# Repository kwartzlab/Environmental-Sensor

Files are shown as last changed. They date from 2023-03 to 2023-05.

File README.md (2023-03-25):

# Kwartzlab Environmental Sensor

The Kwartzlab Environemntal Sensor is a sensor board that is powered by an ESP32 which sends environmental metrics to grafana over wifi.

## Sensors
* [SHTC3 Humidity and Temperature Sensor](datasheets/SHTC3.pdf)
* [BME688 Gas Sensor](datasheets/BME688.pdf)
* [SPS30 Air Quality Sensor](datasheets/SPS30.pdf)
* [Zio Loudness Sensor](https://www.smart-prototyping.com/blog/Zio-Loudness-Sensor-Qwiic-Start-Guide)

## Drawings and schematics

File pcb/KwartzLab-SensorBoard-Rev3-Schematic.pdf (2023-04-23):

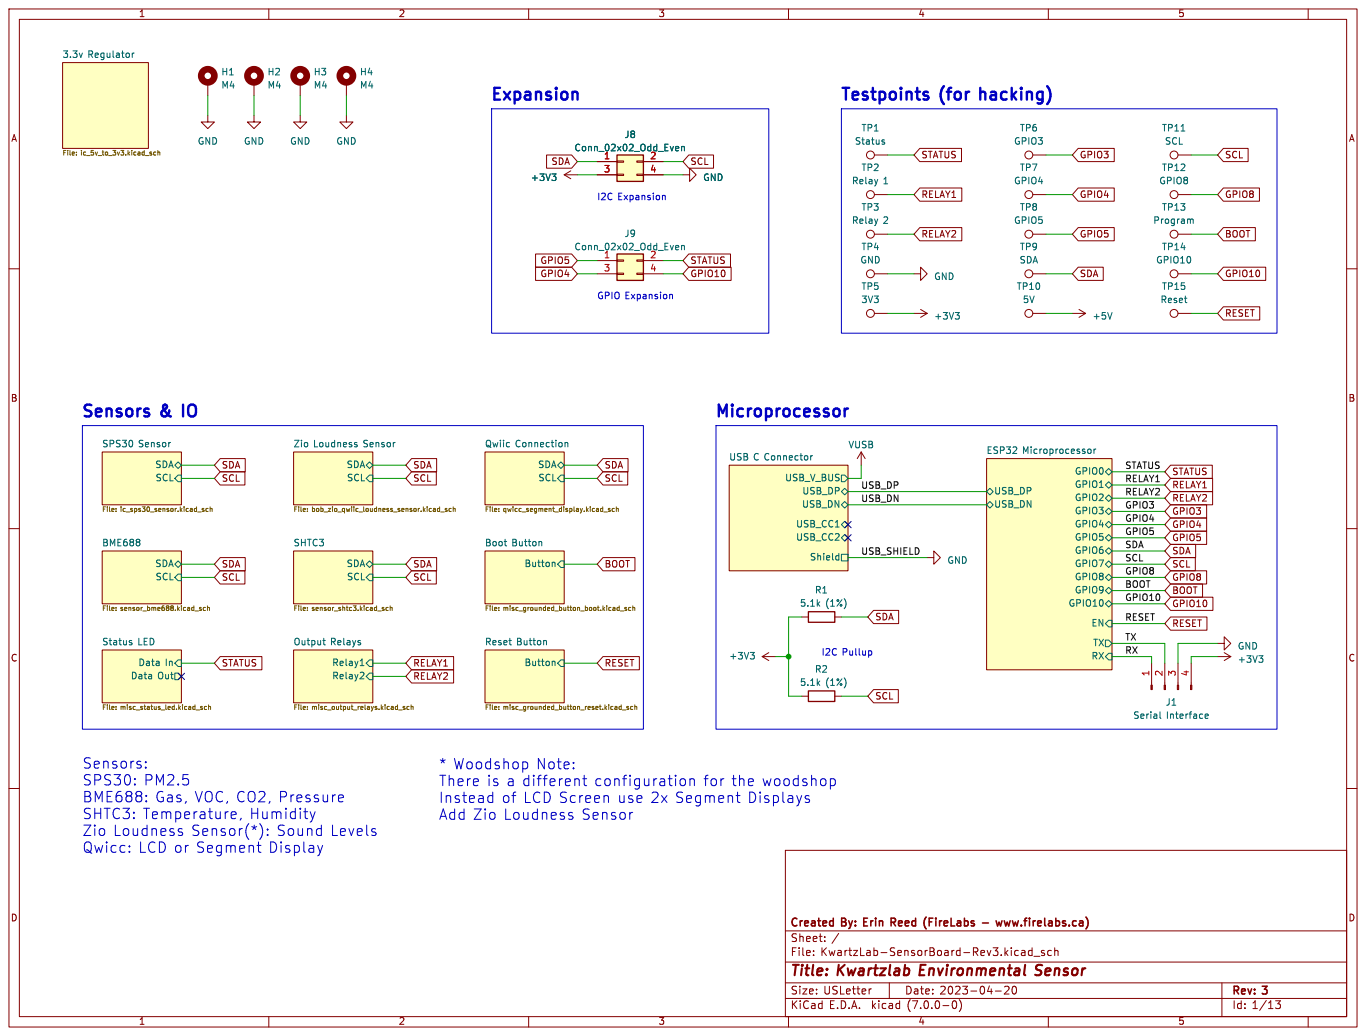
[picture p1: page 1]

File: misc_grounded_button_reset.kicad_sch SCL SDA Qwiic Connection

Zio Loudness Sensor File: bob_zio_qwiic_loudness_sensor.kicad_sch Relay1

STATUS RELAY1 GPIO3 RELAY2 GPIO5 GPIO4 GPIO10 BOOT SCL RESET RX

File: qwicc_segment_display.kicad_sch Button Boot Button

File: misc_output_relays.kicad_sch Data In Data Out Status LED

Sensors:
SPS30: PM2.5
BME688: Gas, VOC, CO2, Pressure
SHTC3: Temperature, Humidity
Zio Loudness Sensor(*): Sound Levels
Qwicc: LCD or Segment Display

Instead of LCD Screen use 2x Segment Displays
Add Zio Loudness Sensor

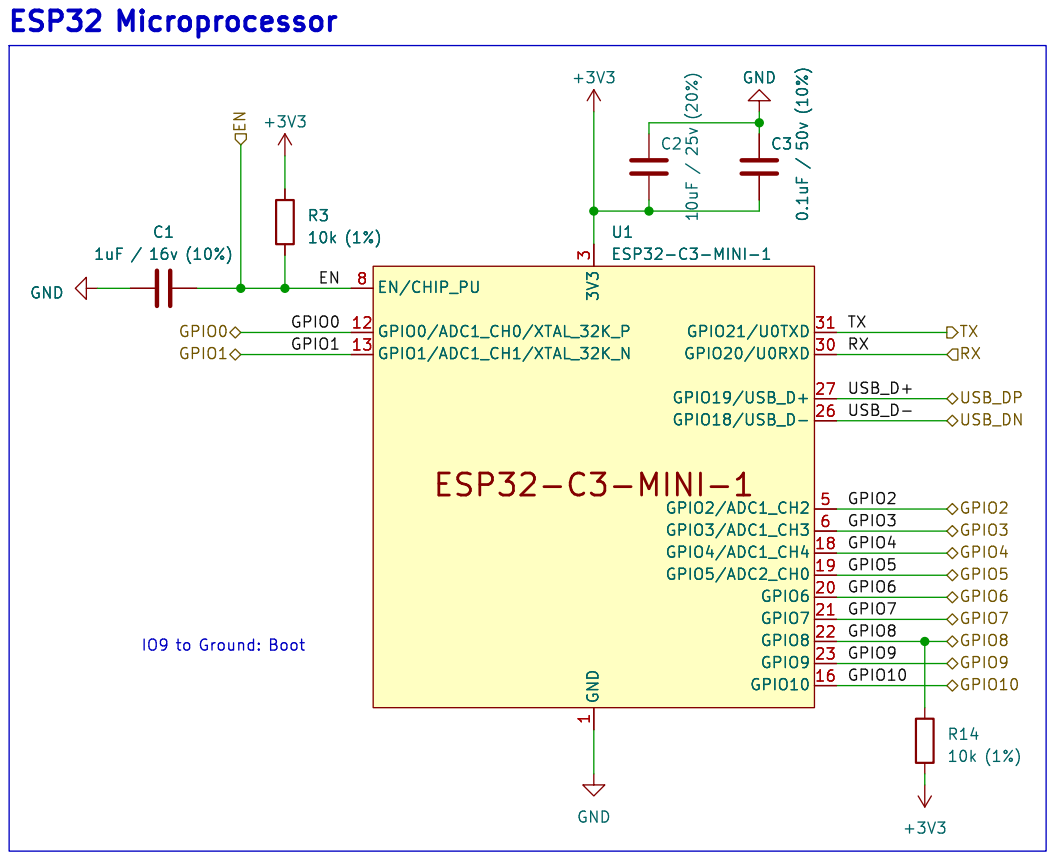
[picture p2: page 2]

IO9 to Ground: Boot ESP32 Microprocessor C1
C3 0.1uF / 50v (10%) U1ESP32-C3-MINI-1 GND

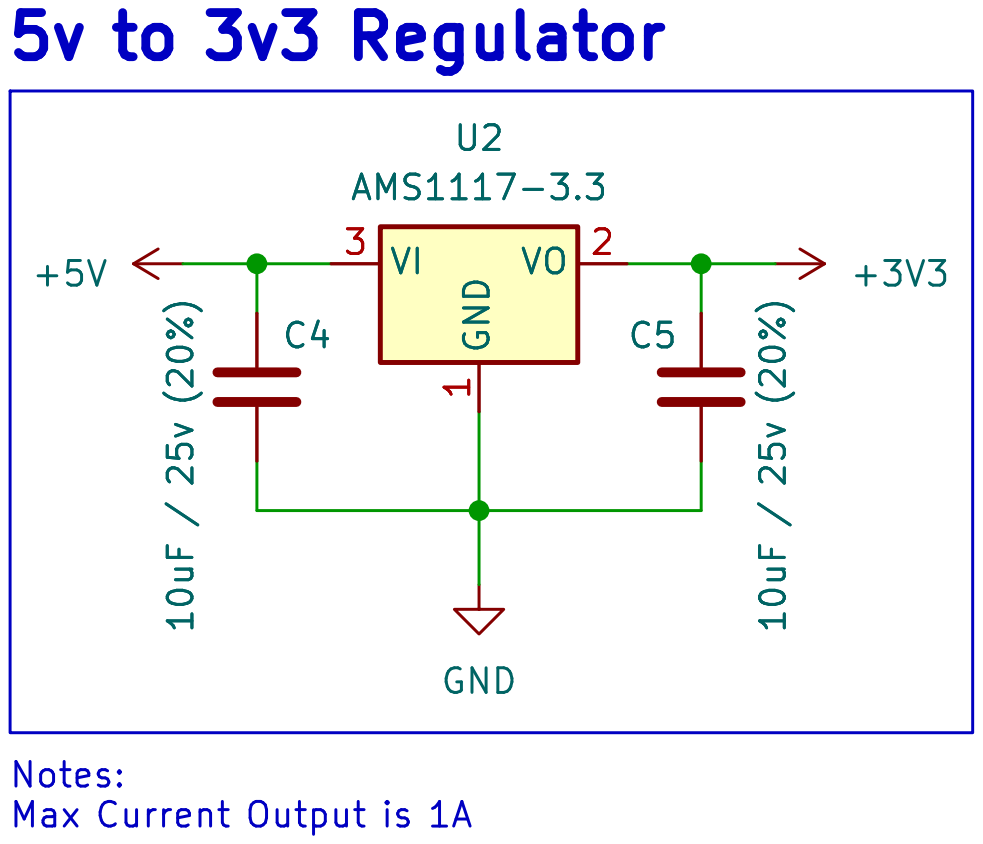
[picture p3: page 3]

1 VO 2 VI 3 U2 AMS1117-3.3 5v to 3v3 Regulator Notes: Max Current Output is 1A C4 10uF / 25v (20%) C5 10uF / 25v (20%) U2 AMS1117-3.3 GND

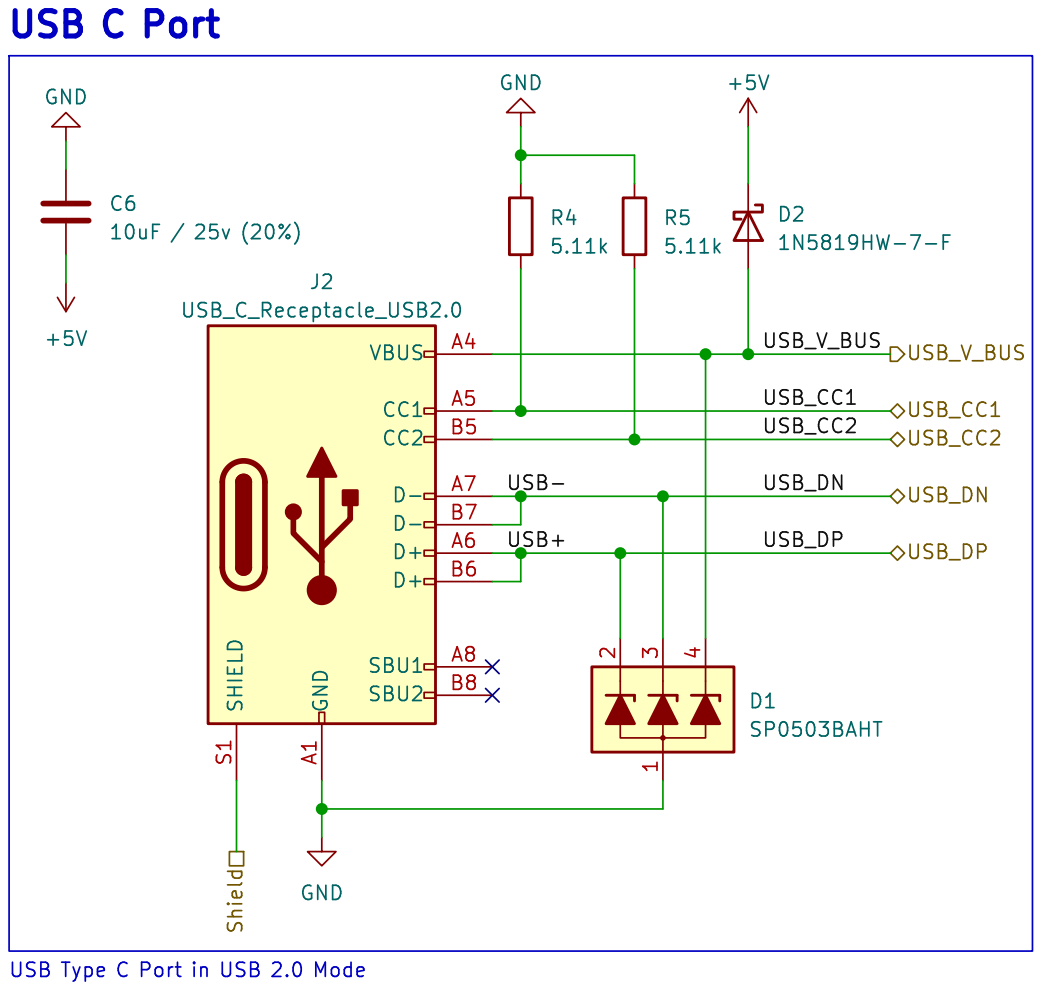
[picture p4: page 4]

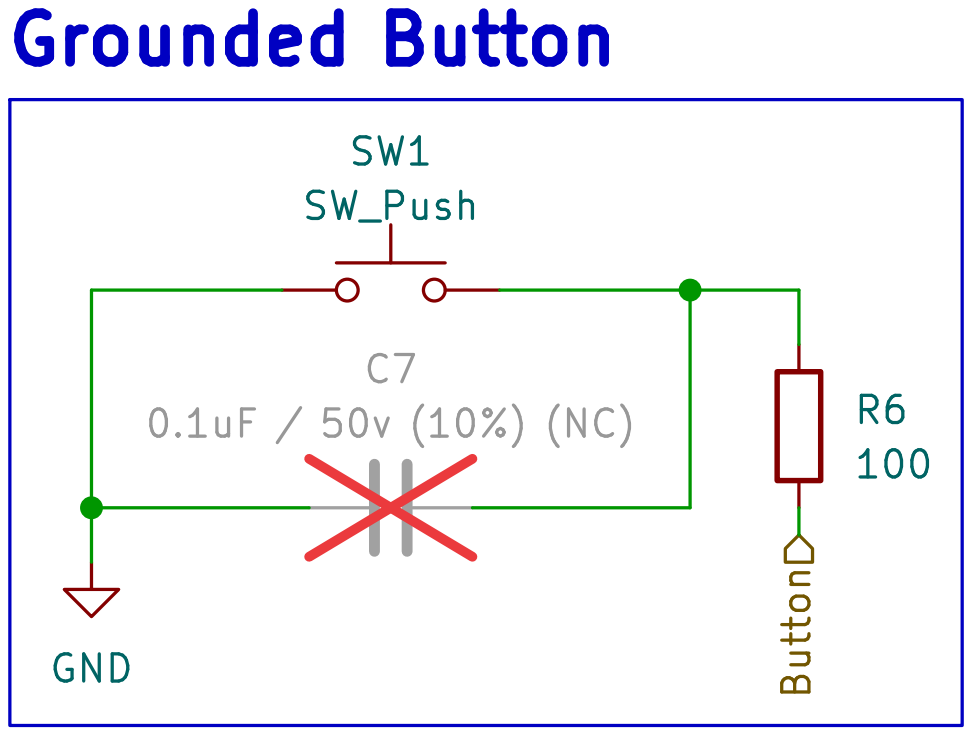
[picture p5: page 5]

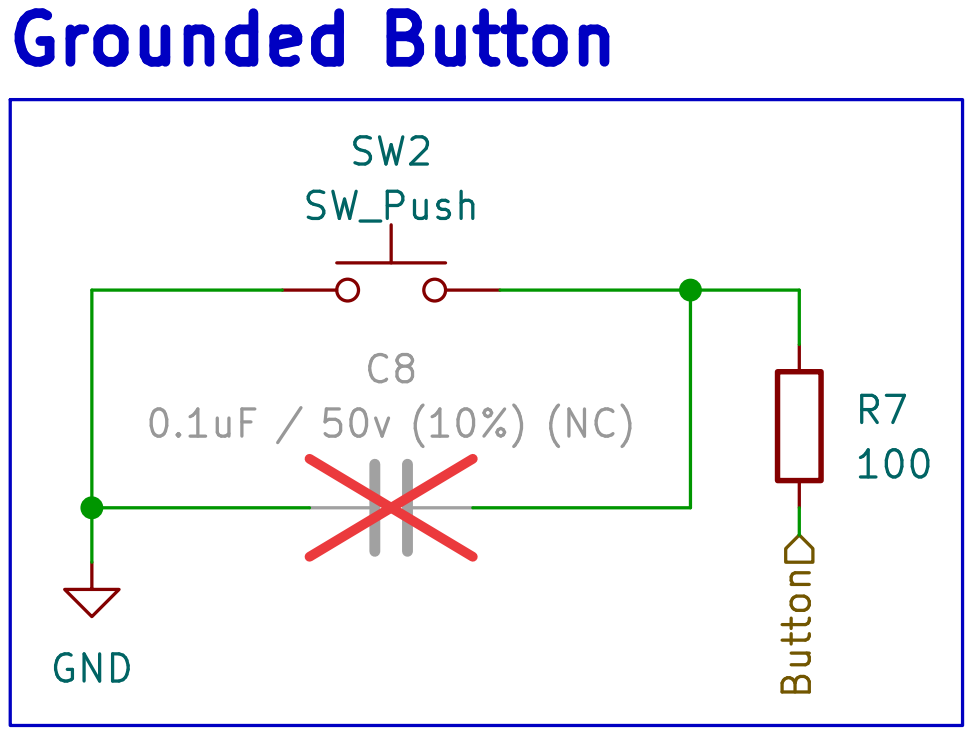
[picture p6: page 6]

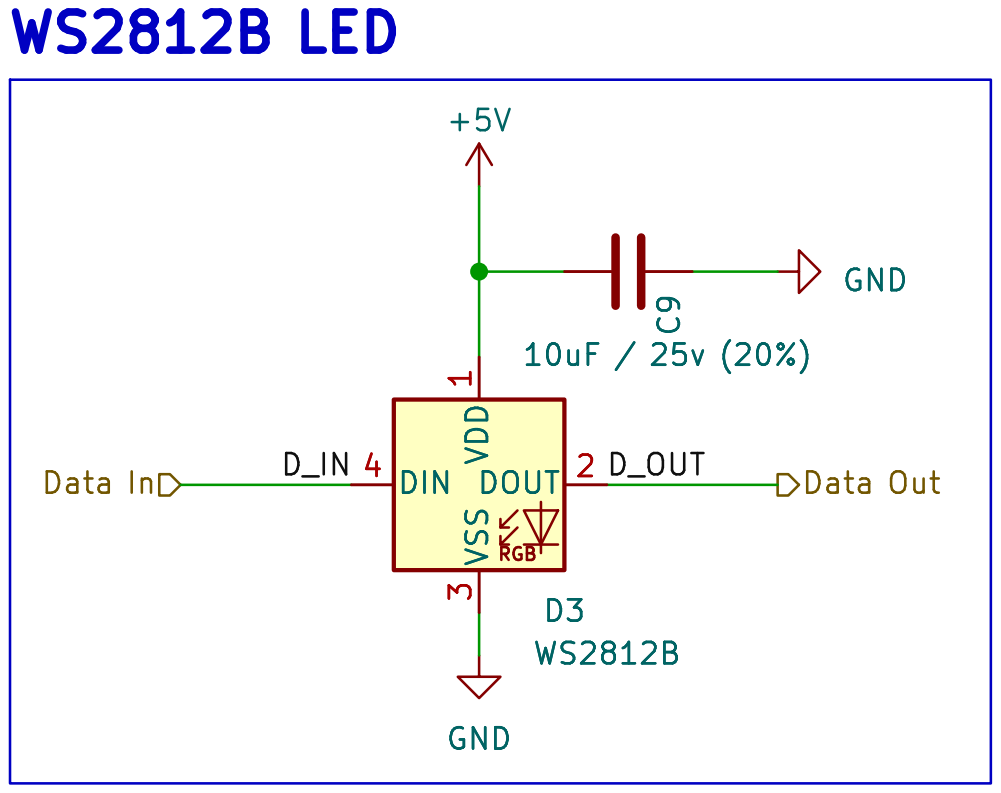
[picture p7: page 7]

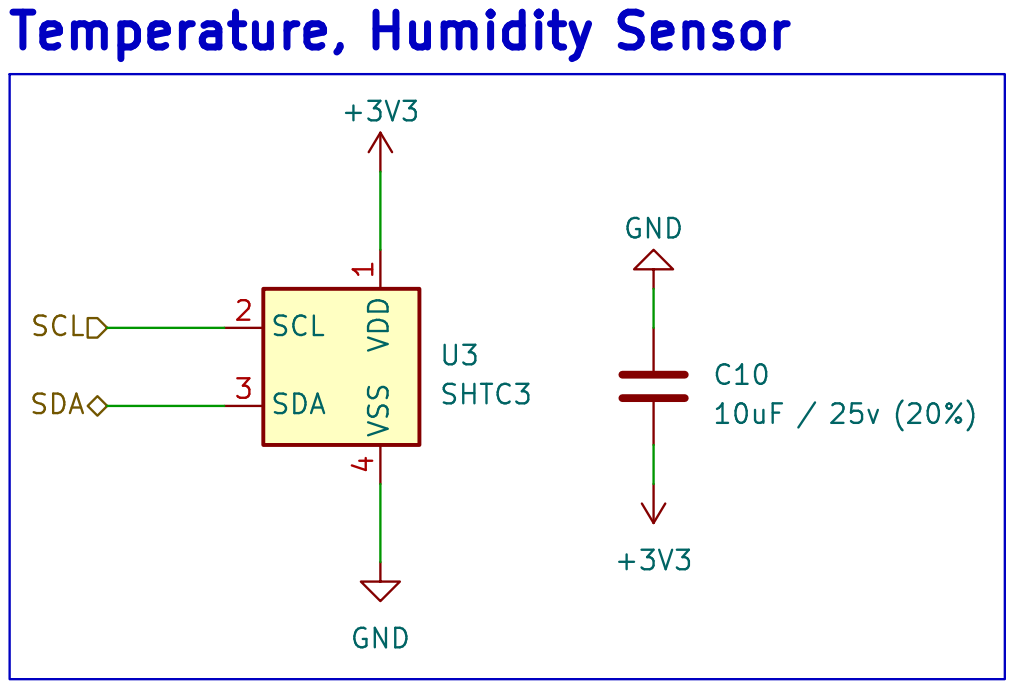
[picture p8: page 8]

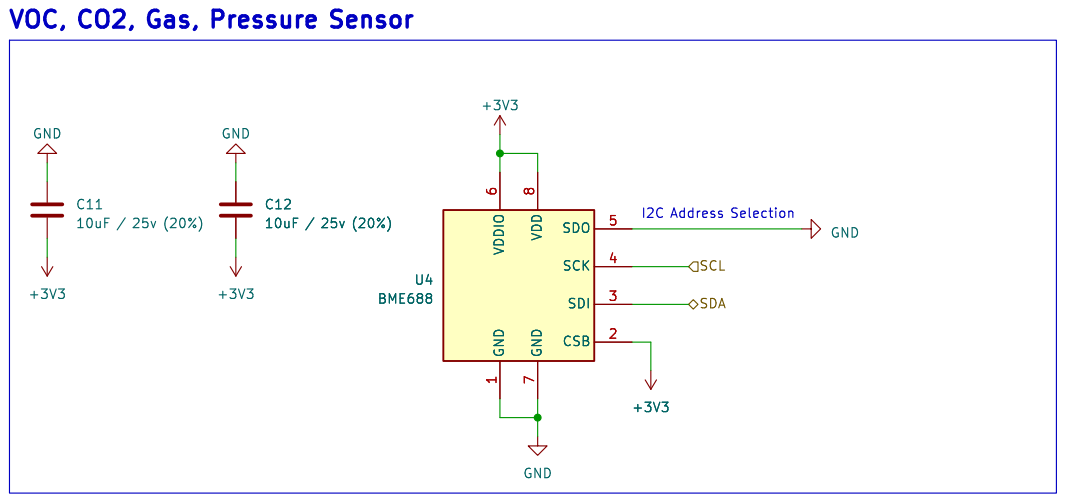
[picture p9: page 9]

1 CSB 2 SDI 3 SCK 4 SDO 5 VDDIO

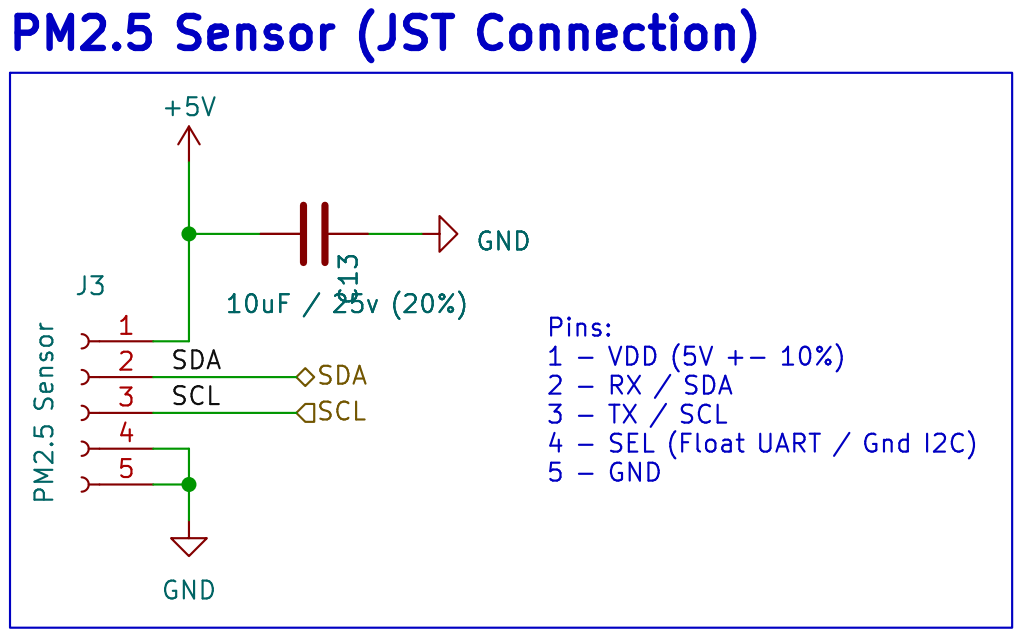
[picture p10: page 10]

SCL SDA PM2.5 Sensor (JST Connection) Pins: 1 - VDD (5V +- 10%) 2 - RX / SDA

4 - SEL (Float UART / Gnd I2C) 5 - GND GND C13 10uF / 25v (20%)

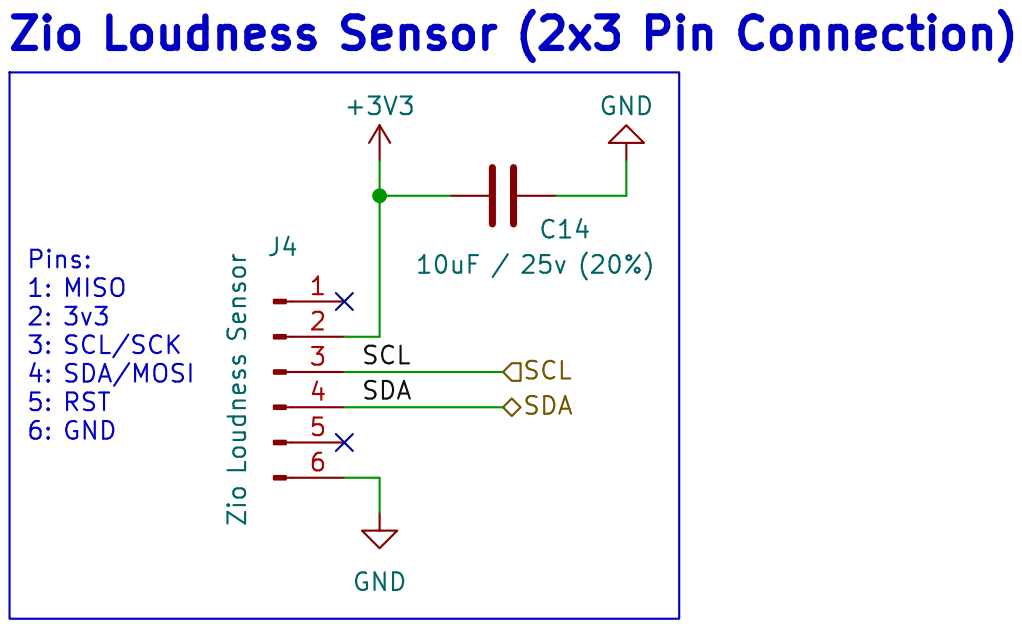
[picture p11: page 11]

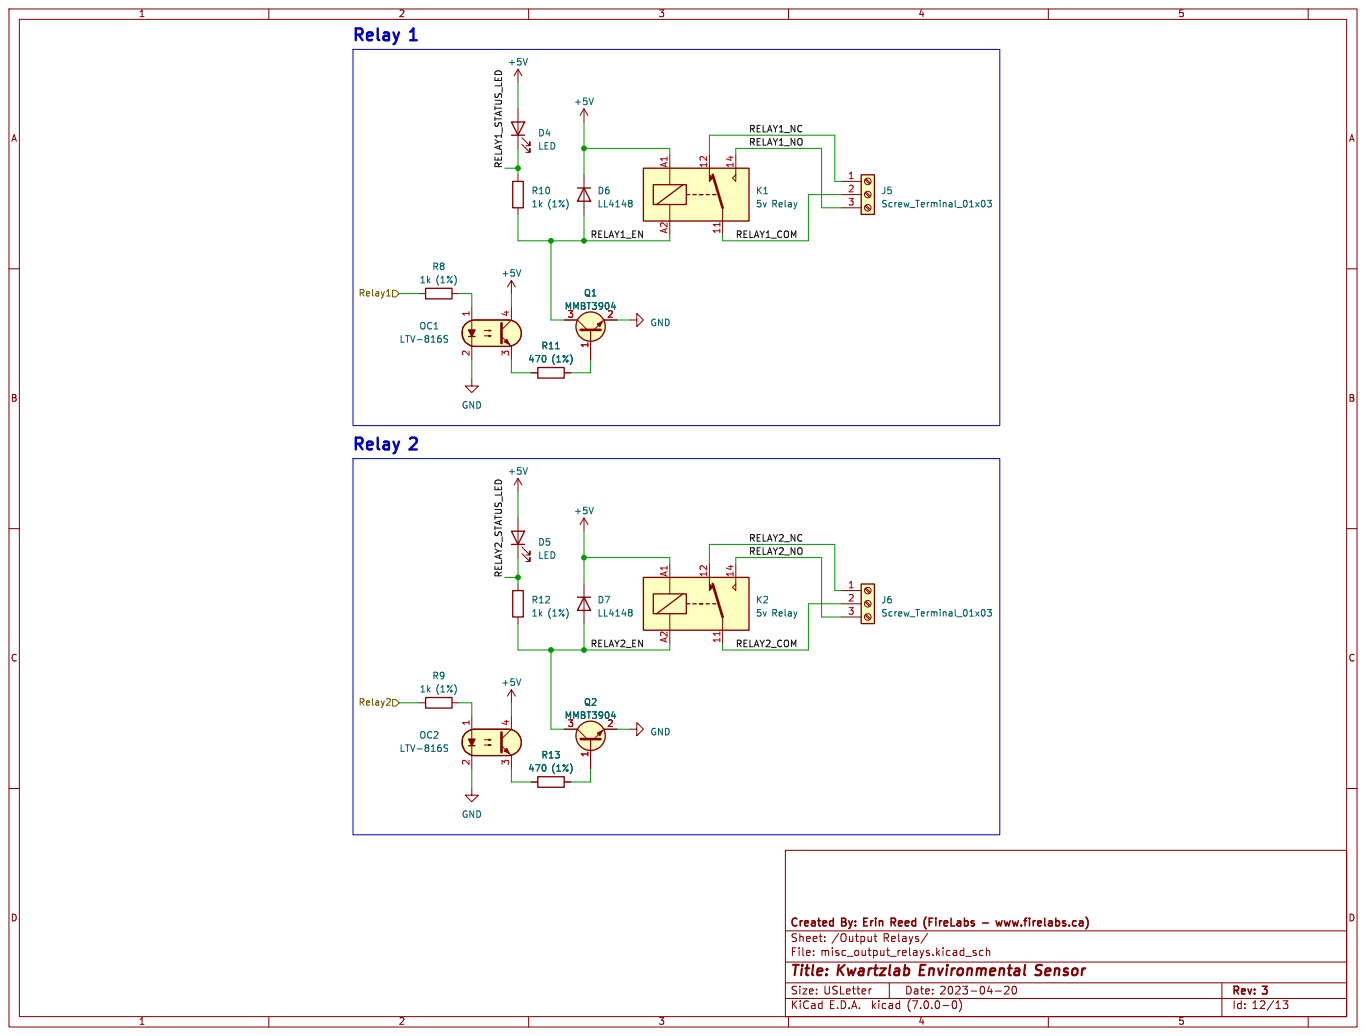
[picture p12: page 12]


10uF / 25v (20%) SCL SDA Qwiic Connector

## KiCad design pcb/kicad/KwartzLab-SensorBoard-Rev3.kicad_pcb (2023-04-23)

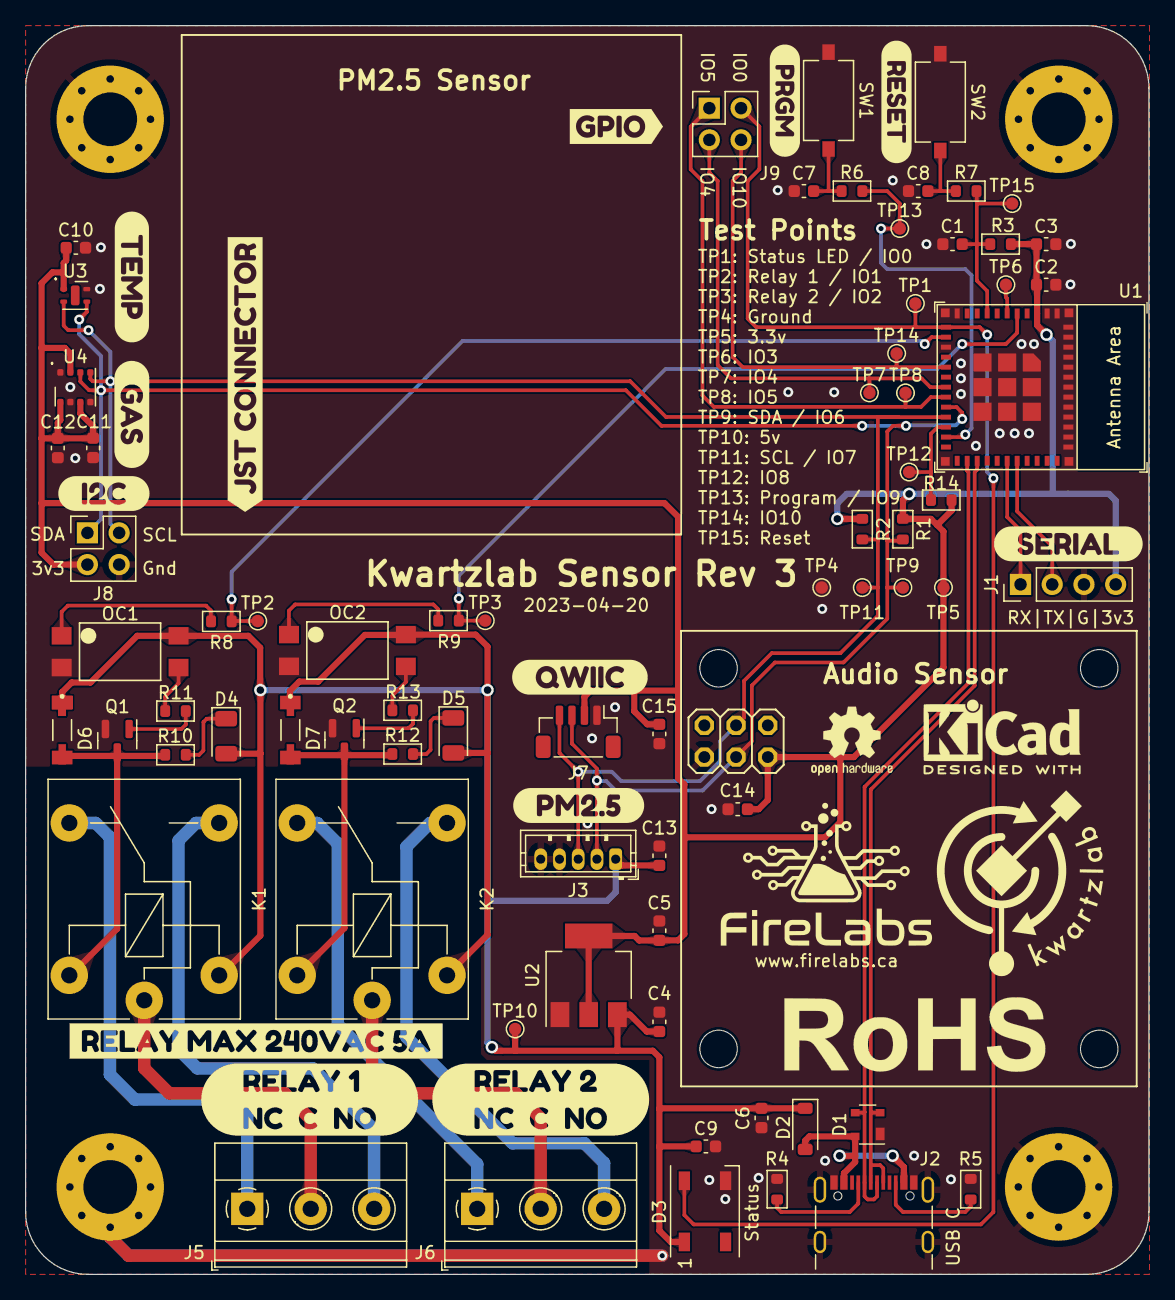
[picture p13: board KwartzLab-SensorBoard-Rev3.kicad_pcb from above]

Board: 2 copper layers, 90.0 x 100.0 mm, 89 parts (0 on the bottom side), 40 nets.

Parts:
C1: 1uF / 16v (10%); C_0603_1608Metric
C2, C4, C5, C6, C9, C10, C11, C12, C13, C14, C15: 10uF / 25v (20%); C_0603_1608Metric
C3: 0.1uF / 50v (10%); C_0603_1608Metric
C7, C8: 0.1uF / 50v (10%) (NC); C_0603_1608Metric
D1: SP0503BAHT; SOT-143
D2: 1N5819HW-7-F; D_SOD-123
D3: WS2812B; LED_WS2812B_PLCC4_5.0x5.0mm_P3.2mm
D4, D5: LED; LED_1206_3216Metric
D6, D7: LL4148; DIO_LL4148
H1, H2, H3, H4: M4; MountingHole_4.3mm_M4_Pad_Via
J1: Serial Interface; PinHeader_1x04_P2.54mm_Vertical
J2: USB_C_Receptacle_USB2.0; USB_C_Receptacle_GCT_USB4105-xx-A_16P_TopMnt_Horizontal
J3: PM2.5 Sensor; JST_ZH_B5B-ZR_1x05_P1.50mm_Vertical
J4: Zio Loudness Sensor; zio_loudness_sensor
J5, J6: Screw_Terminal_01x03; TerminalBlock_Phoenix_MKDS-1,5-3-5.08_1x03_P5.08mm_Horizont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
J7: Qwiic Connector; JST_SH_BM04B-SRSS-TB_1x04-1MP_P1.00mm_Vertical
J8, J9: Conn_02x02_Odd_Even; PinHeader_2x02_P2.54mm_Vertical
K1, K2: 5v Relay; Relay_SPDT_Finder_36.11
OC1, OC2: APC-817A1; SMD4-2.54-4.6X6.5MM
Q1, Q2: MMBT3904; SOT-23
R1, R2: 5.1k (1%); R_0603_1608Metric
R3, R14: 10k (1%); R_0603_1608Metric
R4, R5: 5.11k; R_0603_1608Metric
R6, R7: 100; R_0603_1608Metric
R8, R9, R10, R12: 1k (1%); R_0603_1608Metric
R11, R13: 470 (1%); R_0603_1608Metric
SW1, SW2: SW_Push; SW_Tactile_SPST_NO_Straight_CK_PTS636Sx25SMTRLFS
TP1: Status; TestPoint_Pad_D1.0mm
TP2: Relay 1; TestPoint_Pad_D1.0mm
TP3: Relay 2; TestPoint_Pad_D1.0mm
TP4: GND; TestPoint_Pad_D1.0mm
TP5: 3V3; TestPoint_Pad_D1.0mm
TP6: GPIO3; TestPoint_Pad_D1.0mm
TP7: GPIO4; TestPoint_Pad_D1.0mm
TP8: GPIO5; TestPoint_Pad_D1.0mm
TP9: SDA; TestPoint_Pad_D1.0mm
TP10: 5V; TestPoint_Pad_D1.0mm
TP11: SCL; TestPoint_Pad_D1.0mm
TP12: GPIO8; TestPoint_Pad_D1.0mm
TP13: Program; TestPoint_Pad_D1.0mm
TP14: GPIO10; TestPoint_Pad_D1.0mm
TP15: Reset; TestPoint_Pad_D1.0mm
U1: ESP32-C3-MINI-1
U2: AMS1117-3.3; SOT-223-3_TabPin2
U3: SHTC3; Sensirion_DFN-4-1EP_2x2mm_P1mm_EP0.7x1.6mm
U4: BME688; Bosch_LGA-8_3x3mm_P0.8mm_ClockwisePinNumbering
kibuzzard-64420A01: G***; kibuzzard-64420A01
kibuzzard-64420A6A: G***; kibuzzard-64420A6A
kibuzzard-64420C1B: G***; kibuzzard-64420C1B
kibuzzard-64420C5E: G***; kibuzzard-64420C5E
kibuzzard-64420C16: G***; kibuzzard-64420C16
kibuzzard-64420C24: G***; kibuzzard-64420C24
kibuzzard-64420C54: G***; kibuzzard-64420C54
kibuzzard-64420CBE: G***; kibuzzard-64420CBE
kibuzzard-64420CCA: G***; kibuzzard-64420CCA
kibuzzard-64420E8B: G***; kibuzzard-64420E8B
kibuzzard-644209FA: G***; kibuzzard-644209FA
kibuzzard-644479D4: G***; kibuzzard-644479D4
kibuzzard-64444232: G***; kibuzzard-64444232

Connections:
+3V3: C2.1, C3.1, C5.1, C10.1, C11.1, C12.1, C14.1, C15.2, J1.4, J4.2, J7.2, J8.3, R1.1, R2.1, R3.1, R14.2, TP5.1, U1.3 (3V3), U2.2 (VO), U3.1 (VDD), U4.2 (CSB), U4.6 (VDDIO), U4.8 (VDD)
+5V: C4.1, C6.1, C9.1, C13.1, D2.1 (K), D3.1 (VDD), D4.2 (A), D5.2 (A), D6.1, D7.1, J3.1, K1.A1, K2.A1, OC1.4, OC2.4, TP10.1, U2.3 (VI)
/Output Relays/RELAY1_COM: J5.2, K1.11
/Output Relays/RELAY1_EN: D6.2, K1.A2, Q1.3 (C), R10.2
/Output Relays/RELAY1_NC: J5.1, K1.12
/Output Relays/RELAY1_NO: J5.3, K1.14
/Output Relays/RELAY1_STATUS_LED: D4.1 (K), R10.1
/Output Relays/RELAY2_COM: J6.2, K2.11
/Output Relays/RELAY2_EN: D7.2, K2.A2, Q2.3 (C), R12.2
/Output Relays/RELAY2_NC: J6.1, K2.12
/Output Relays/RELAY2_NO: J6.3, K2.14
/Output Relays/RELAY2_STATUS_LED: D5.1 (K), R12.1
/RX: J1.1, U1.30 (GPIO20/U0RXD)
/TX: J1.2, U1.31 (GPIO21/U0TXD)
/USB C Connector/USB_CC1: J2.A5 (CC1), R4.2
/USB C Connector/USB_CC2: J2.B5 (CC2), R5.2
/USB_DN: D1.3 (L2), J2.A7 (D-), J2.B7 (D-), U1.26 (GPIO18/USB_D-)
/USB_DP: D1.2 (L1), J2.A6 (D+), J2.B6 (D+), U1.27 (GPIO19/USB_D+)
BOOT: R6.2, TP13.1, U1.23 (GPIO9)
GND: C1.1, C2.2, C3.2, C4.2, C5.2, C6.2, C7.1, C8.1, C9.2, C10.2, C11.2, C12.2, C13.2, C14.2, C15.1, D1.1 (VN), D3.3 (VSS), H1.1, H2.1, H3.1, H4.1, J1.3, J2.A1 (GND), J2.A12 (GND), J2.B1 (GND), J2.B12 (GND), J2.S1 (SHIELD), J3.4, J3.5, J4.6, J7.1, J8.4, OC1.2, OC2.2, Q1.2 (E), Q2.2 (E), R4.1, R5.1, SW1.1, SW2.1, TP4.1, U1.1 (GND), U1.2 (GND), U1.11 (GND), U1.14 (GND), U1.36 (GND), U1.37 (GND), U1.38 (GND), U1.39 (GND), U1.40 (GND), U1.41 (GND), U1.42 (GND), U1.43 (GND), U1.44 (GND), U1.45 (GND), U1.46 (GND), U1.47 (GND), U1.48 (GND), U1.49 (GND), U1.50 (GND), U1.51 (GND), U1.52 (GND), U1.53 (GND), U2.1 (GND), U3.4 (VSS), U4.1 (GND), U4.5 (SDO), U4.7 (GND)
GPIO3: TP6.1, U1.6 (GPIO3/ADC1_CH3)
GPIO4: J9.3, TP7.1, U1.18 (GPIO4/ADC1_CH4)
GPIO5: J9.1, TP8.1, U1.19 (GPIO5/ADC2_CH0)
GPIO8: R14.1, TP12.1, U1.22 (GPIO8)
GPIO10: J9.4, TP14.1, U1.16 (GPIO10)
unnamed: C7.2, R6.1, SW1.2
unnamed: C8.2, R7.1, SW2.2
unnamed: OC1.1, R8.2
unnamed: OC1.3, R11.2
unnamed: OC2.1, R9.2
unnamed: OC2.3, R13.2
unnamed: Q1.1 (B), R11.1
unnamed: Q2.1 (B), R13.1
RELAY1: R8.1, TP2.1, U1.13 (GPIO1/ADC1_CH1/XTAL_32K_N)
RELAY2: R9.1, TP3.1, U1.5 (GPIO2/ADC1_CH2)
RESET: C1.2, R3.2, R7.2, TP15.1, U1.8 (EN/CHIP_PU)
SCL: J3.3, J4.3, J7.4, J8.2, R2.2, TP11.1, U1.21 (GPIO7), U3.2 (SCL), U4.4 (SCK)
SDA: J3.2, J4.4, J7.3, J8.1, R1.2, TP9.1, U1.20 (GPIO6), U3.3 (SDA), U4.3 (SDI)
STATUS: D3.4 (DIN), J9.2, TP1.1, U1.12 (GPIO0/ADC1_CH0/XTAL_32K_P)
VBUS: D1.4 (L3), D2.2 (A), J2.A4 (VBUS), J2.A9 (VBUS), J2.B4 (VBUS), J2.B9 (VBUS)

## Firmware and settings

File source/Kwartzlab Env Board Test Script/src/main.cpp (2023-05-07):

/* Test script to test the Kwartzlab Environmental Sensor Board */

// Neo Pixel
#define STATUS_LED 0
#define TOTAL_LEDS 1

// GPIO Pins
#define RELAY1 1
#define RELAY2 2
#define GPIO3 3
#define GPIO4 4
#define GPIO5 5
#define I2C_SDA 6
#define I2C_SCL 7
#define GPIO8 8
#define PROGRAM_BUTTON 9
#define GPIO10 10

// I2C Addresses
#define SEGMENT_DISPLAY_1 0x71
#define SEGMENT_DISPLAY_2 0x72
#define BME688_SENSOR 0x76
#define SHTC3_SENSOR 0x70
#define SPS30_SENSOR 0x69
#define ZIO_LOUDNESS_SENSOR 0x38

#define BIAS_LEVEL 400

// Includes
#include <Wire.h>
#include <i2cdetect.h>

#include <Ticker.h>
Ticker checkBME688Sensor;
Ticker checkSPS30Sensor;
Ticker checkSHTC3Sensor;
Ticker checkZioSensor;
Ticker toggleGPIO;

#include <SparkFun_Alphanumeric_Display.h>
HT16K33 segmentDisplay;

#include <Adafruit_NeoPixel.h>
Adafruit_NeoPixel statusLed(TOTAL_LEDS, STATUS_LED, NEO_GRB + NEO_KHZ800);

#include <bsec2.h>
Bsec2 bme688Sensor;

#include <sps30.h>

#include <Adafruit_SHTC3.h>
Adafruit_SHTC3 shtc3Sensor = Adafruit_SHTC3();

#include <zio.h>
ZIO zioSensor;

//  Variables
uint32_t chipId = 0;
uint32_t currentScreen = 0;

// I2C Device Status
bool statusLed_output = false;
bool displayEnabled = false;
bool bme688SensorEnabled = false;
bool shtc3SensorEnabled = false;
bool sps30SensorEnabled = false;
bool zioLoudnessSensorEnabled = false;

bool gpioOutput = false;

void IRAM_ATTR buttonPress() {
  int buttonVal = digitalRead(PROGRAM_BUTTON);
  Serial.print("Button changed (");
  Serial.print(buttonVal);
  Serial.println(")");
}

void scanI2CBus() {
  Serial.println("Scanning I2C address range from 0x03 to 0x77\n");
  i2cdetect();
}

void checkBsecStatus(Bsec2 bsec) {
    if (bsec.status < BSEC_OK) {
      Serial.println("BSEC error code : " + String(bsec.status));
    } else if (bsec.status > BSEC_OK) {
      Serial.println("BSEC warning code : " + String(bsec.status));
    }

    if (bsec.sensor.status < BME68X_OK) {
      Serial.println("BME68X error code : " + String(bsec.sensor.status));
    } else if (bsec.sensor.status > BME68X_OK) {
      Serial.println("BME68X warning code : " + String(bsec.sensor.status));
    }
}

float sensor_bme688_iaq;
float sensor_bme688_co2;
float sensor_bme688_voc;
/**
 * @brief : This function is called by the BSEC library when a new output is available
 * @param[in] input     : BME68X sensor data before processing
 * @param[in] outputs   : Processed BSEC BSEC output data
 * @param[in] bsec      : Instance of BSEC2 calling the callback
 */
void bme688SensorDataCallback(const bme68xData data, const bsecOutputs outputs, Bsec2 bsec) {
  Serial.println(">>> Data input...");

  if (!outputs.nOutputs) {
      return;
  }

  Serial.println("BSEC outputs:\ntimestamp = " + String((int) (outputs.output[0].time_stamp / INT64_C(1000000))));
  for (uint8_t i = 0; i < outputs.nOutputs; i++) {
    const bsecData output  = outputs.output[i];
    switch (output.sensor_id) {
      case BSEC_OUTPUT_IAQ:
        sensor_bme688_iaq = output.signal;
        Serial.println("iaq = " + String(output.signal));
        Serial.println("iaq accuracy = " + String((int) output.accuracy));
        break;
      case BSEC_OUTPUT_RAW_TEMPERATURE:
        Serial.println("temperature = " + String(output.signal));
        break;
      case BSEC_OUTPUT_RAW_PRESSURE:
        Serial.println("pressure = " + String(output.signal));
        break;
      case BSEC_OUTPUT_RAW_HUMIDITY:
        Serial.println("humidity = " + String(output.signal));
        break;
      case BSEC_OUTPUT_RAW_GAS:
        Serial.println("gas resistance = " + String(output.signal));
        break;
      case BSEC_OUTPUT_STABILIZATION_STATUS:
        Serial.println("stabilization status = " + String(output.signal));
        break;
      case BSEC_OUTPUT_RUN_IN_STATUS:
        Serial.println("run in status = " + String(output.signal));
        break;
      case BSEC_OUTPUT_BREATH_VOC_EQUIVALENT:
        sensor_bme688_voc = output.signal;
        Serial.println("breath voc equivalent = " + String(output.signal));
        break;
      case BSEC_OUTPUT_CO2_EQUIVALENT:
        sensor_bme688_co2 = output.signal;
        Serial.println("co2 equivalent = " + String(output.signal));
      default:
        break;
    }
  }
}

void checkBME688SensorTick() {
  // BME688
  if (!bme688Sensor.run()) {
    checkBsecStatus(bme688Sensor);
  }
}

float sensor_sps30_pm25;
float sensor_sps30_particle_size;
void checkSPS30SensorTick() {
  // SPS30
  struct sps30_measurement m;
  char serial[SPS30_MAX_SERIAL_LEN];
  uint16_t data_ready;
  int16_t ret;

  do {
    ret = sps30_read_data_ready(&data_ready);
    if (ret < 0) {
      Serial.print("error reading data-ready flag: ");
      Serial.println(ret);
    } else if (!data_ready)
      Serial.print("data not ready, no new measurement available\n");
    else
      break;
    delay(100); /* retry in 100ms */
  } while (1);

  ret = sps30_read_measurement(&m);
  if (ret < 0) {
    Serial.print("error reading measurement\n");
  } else {
    sensor_sps30_pm25 = m.mc_2p5;
    sensor_sps30_particle_size = m.typical_particle_size;

    Serial.print("PM  1.0: ");
    Serial.println(m.mc_1p0);
    Serial.print("PM  2.5: ");
    Serial.println(m.mc_2p5);
    Serial.print("PM  4.0: ");
    Serial.println(m.mc_4p0);
    Serial.print("PM 10.0: ");
    Serial.println(m.mc_10p0);

    Serial.print("NC  0.5: ");
    Serial.println(m.nc_0p5);
    Serial.print("NC  1.0: ");
    Serial.println(m.nc_1p0);
    Serial.print("NC  2.5: ");
    Serial.println(m.nc_2p5);
    Serial.print("NC  4.0: ");
    Serial.println(m.nc_4p0);
    Serial.print("NC 10.0: ");
    Serial.println(m.nc_10p0);

    Serial.print("Typical partical size: ");
    Serial.println(m.typical_particle_size);
  }
}


float sensor_shtc3_temperature;
float sensor_shtc3_humidity;
void checkSHTC3SensorTick() {
  sensors_event_t humidity, temp;
  shtc3Sensor.getEvent(&humidity, &temp);
  sensor_shtc3_temperature = temp.temperature;
  sensor_shtc3_humidity = humidity.relative_humidity;
  Serial.print("Temperature: "); Serial.print(temp.temperature); Serial.println(" degrees C");
  Serial.print("Humidity: "); Serial.print(humidity.relative_humidity); Serial.println("% rH");
}

float sensor_zio_db;
void checkZioSensorTick() {
  zioSensor.ledOn();
  delay(100);

  int sumSquare;
  for (int i = 0; i < 100; i++) {
    int capture_ac = zioSensor.getValue() - BIAS_LEVEL;
    sumSquare += capture_ac * capture_ac;
  }
  int rms = sqrt(sumSquare / 100);

  sensor_zio_db = rms;
  Serial.print("ADC_Value:  ");
  Serial.println(rms,DEC);
  zioSensor.ledOff();
}

void toggleGPIOTick() {
  Serial.print("Setting GPIO to ");
  Serial.println(gpioOutput ? "HIGH" : "LOW");

  digitalWrite(3, gpioOutput ? HIGH : LOW);
  digitalWrite(4, gpioOutput ? HIGH : LOW);
  digitalWrite(5, gpioOutput ? HIGH : LOW);
  digitalWrite(8, gpioOutput ? HIGH : LOW);
  digitalWrite(10, gpioOutput ? HIGH : LOW);
  if (gpioOutput)
    gpioOutput = false;
  else
    gpioOutput = true;
}

void showDisplayMessage(String message) {
  if (message.length() <= 8) {
    segmentDisplay.print(message);
    delay(1000);
  } else {
    for (int i = 0; i < message.length() - 7; i++) {
      segmentDisplay.print(message.substring(i, i + 8));
      delay(400);
      if (i == 0)
        delay(1000);
    }
  }
}

void setup() {
  // Setup Serial
  Serial.begin(115200);
  while (!Serial) delay(2000);

  // Setup Relay GPIO Pins
  pinMode(RELAY1, OUTPUT); // Relay 1
  pinMode(RELAY2, OUTPUT); // Relay 2

  // Setup Generic GPIO Pins
  pinMode(GPIO3, OUTPUT); // GPIO3
  pinMode(GPIO4, OUTPUT); // GPIO4
  pinMode(GPIO5, OUTPUT); // GPIO5
  pinMode(GPIO8, OUTPUT); // GPIO6
  pinMode(GPIO10, OUTPUT); // GPIO10

  delay(5000);

  // Setup Input GPIO Pin
  pinMode(PROGRAM_BUTTON, INPUT_PULLUP); // Program Button

  // Setup interrupt
  attachInterrupt(9, buttonPress, CHANGE);

  // Setup I2C
  Wire.begin(I2C_SDA, I2C_SCL);

  // Setup NeoPixel & Clear
  statusLed.begin();
  statusLed.clear();
  statusLed.show();
  statusLed_output = true; // There really isn't anything to check for...

  // Setup SPS30
  int16_t ret;
  uint8_t auto_clean_days = 4;
  uint32_t auto_clean;

  sensirion_i2c_init();

  if (sps30_probe() == 0) {
    sps30SensorEnabled = true;

    ret = sps30_set_fan_auto_cleaning_interval_days(auto_clean_days);
    if (ret) {
      Serial.print("error setting the auto-clean interval: ");
      Serial.println(ret);
    }

    ret = sps30_start_measurement();
    if (ret < 0) {
      Serial.print("error starting measurement\n");
    }
  }

  // Setup Alphanumeric Display
  if (segmentDisplay.begin(SEGMENT_DISPLAY_1, SEGMENT_DISPLAY_2)) {
    displayEnabled = true;
    segmentDisplay.setBrightness(5);
  } else {
    statusLed.setPixelColor(0, statusLed.Color(255, 0, 0));
    statusLed.show();
    if (digitalRead(PROGRAM_BUTTON))
      exit(1);
    else {
      statusLed.clear();
      statusLed.show();
    }
  }

  // Setup BME688 Sensor
  if (bme688Sensor.begin(BME688_SENSOR, Wire)) {
    bme688SensorEnabled = true;

    bsecSensor sensorList[] = {
      BSEC_OUTPUT_IAQ,
      BSEC_OUTPUT_RAW_TEMPERATURE,
      BSEC_OUTPUT_RAW_PRESSURE,
      BSEC_OUTPUT_RAW_HUMIDITY,
      BSEC_OUTPUT_STABILIZATION_STATUS,
      BSEC_OUTPUT_RUN_IN_STATUS,
      BSEC_OUTPUT_CO2_EQUIVALENT,
      BSEC_OUTPUT_BREATH_VOC_EQUIVALENT
    };

    if (!bme688Sensor.updateSubscription(sensorList, ARRAY_LEN(sensorList), BSEC_SAMPLE_RATE_LP)) {
      bme688SensorEnabled = false;
      checkBsecStatus(bme688Sensor);
    }

    //if (bme688SensorEnabled)
    bme688Sensor.attachCallback(bme688SensorDataCallback);
  } else {
    Serial.println("Failed to setup the BME688 Sensor");
  }

  // Setup SHTC3 Sensor
  if (shtc3Sensor.begin()) {
    shtc3SensorEnabled = true;
  }

  // Setup Zio Sensor
  if (zioSensor.begin(ZIO_DEFAULT_ADDRESS, Wire)) {
    zioLoudnessSensorEnabled = true;
  }

  // Display Build info
  Serial.println("Kwartzlab Environmental Sensor Test App");
  Serial.println("Revision 1, Built 04/05/23");
  Serial.println("Created By: FireLabs - www.firelabs.ca");
  segmentDisplay.print("ENV TEST");
  delay(1000);
  segmentDisplay.print("REV 1");
  delay(1000);
  segmentDisplay.print("04/05/23");
  delay(1000);
  segmentDisplay.print("FIRELABS");
  delay(1000);

  delay(5000);
  // Test LED
  segmentDisplay.print("LED RED");
  Serial.println("Testing Status Led - RED");
  statusLed.setPixelColor(0, statusLed.Color(255, 0, 0));
  statusLed.show();
  delay(1000);
  segmentDisplay.print("LED GRN");
  Serial.println("Testing Status Led - GREEN");
  statusLed.setPixelColor(0, statusLed.Color(0, 255, 0));
  statusLed.show();
  delay(1000);
  segmentDisplay.print("LED BLUE");
  Serial.println("Testing Status Led - BLUE");
  statusLed.setPixelColor(0, statusLed.Color(0, 0, 255));
  statusLed.show();
  delay(1000);
  segmentDisplay.print("LED WHT");
  Serial.println("Testing Status Led - WHITE");
  statusLed.setPixelColor(0, statusLed.Color(255, 255, 255));
  statusLed.show();
  delay(1000);
  statusLed.clear();
  statusLed.show();
  segmentDisplay.print("DONE");

  delay(5000);
  // Test Relays
  segmentDisplay.print("RELAY *O");
  Serial.println("Testing Left Relay - On");
  digitalWrite(RELAY1, HIGH);
  delay(1000);
  segmentDisplay.print("RELAY OO");
  Serial.println("Testing Left Relay - Off");
  digitalWrite(RELAY1, LOW);
  delay(1000);
  segmentDisplay.print("RELAY O*");
  Serial.println("Testing Right Relay - On");
  digitalWrite(RELAY2, HIGH);
  delay(1000);
  segmentDisplay.print("RELAY OO");
  Serial.println("Testing Right Relay - Off");
  digitalWrite(RELAY2, LOW);
  delay(1000);
  segmentDisplay.print("RELAY **");
  Serial.println("Testing Both Relays - On");
  digitalWrite(RELAY1, HIGH);
  digitalWrite(RELAY2, HIGH);
  delay(1000);
  segmentDisplay.print("RELAY OO");
  Serial.println("Testing Both Relays - Off");
  digitalWrite(RELAY1, LOW);
  digitalWrite(RELAY2, LOW);
  delay(1000);
  segmentDisplay.print("DONE");

  delay(5000);


  // Show ESP32 Info
  for(int i=0; i<17; i=i+8) {
    chipId |= ((ESP.getEfuseMac() >> (40 - i)) & 0xff) << i;
  }

  Serial.printf("ESP32 Chip model = %s Rev %d\n", ESP.getChipModel(), ESP.getChipRevision());
  Serial.printf("This chip has %d cores\n", ESP.getChipCores());
  Serial.print("Chip ID: "); Serial.println(chipId);

  // Enable Timers
  checkBME688Sensor.attach(.1, checkBME688SensorTick);
  checkSPS30Sensor.attach(15, checkSPS30SensorTick);
  checkSHTC3Sensor.attach(15, checkSHTC3SensorTick);
  checkZioSensor.attach(15, checkZioSensorTick);
  toggleGPIO.attach(2, toggleGPIOTick);

  // Show Status Report
  Serial.println("Status Report:");
  Serial.print("Status LED: "); Serial.println(statusLed_output ? "true" : "false");
  Serial.print("Display Enabled: "); Serial.println(displayEnabled ? "true" : "false");
  Serial.print("BME688: "); Serial.println(bme688SensorEnabled ? "true" : "false");
  Serial.print("SHTC3: "); Serial.println(shtc3SensorEnabled ? "true" : "false");
  Serial.print("SPS30: "); Serial.println(sps30SensorEnabled ? "true" : "false");
  Serial.print("Zio Sensor: "); Serial.println(zioLoudnessSensorEnabled ? "true" : "false");
}

void loop() {
  char value[32];
  switch (currentScreen) {
    case 1:
      snprintf(value, 32, "TEMPERATURE %.0fc", sensor_shtc3_temperature);
      showDisplayMessage(value);
      break;
    case 2:
      snprintf(value, 32, "HUMIDITY %.0f%%", sensor_shtc3_humidity);
      showDisplayMessage(value);
      break;
    case 3:
      snprintf(value, 32, "NOISE %.0fdb", sensor_zio_db);
      showDisplayMessage(value);
      break;
    case 4:
      snprintf(value, 32, "AIR QUALITY %.0f", sensor_bme688_iaq);
      showDisplayMessage(value);
      break;
    case 5:
      snprintf(value, 32, "CO2 %.0f", sensor_bme688_co2);
      showDisplayMessage(value);
      break;
    case 6:
      snprintf(value, 32, "VOC %.0f", sensor_bme688_voc);
      showDisplayMessage(value);
      break;
    case 7:
      snprintf(value, 32, "PM2.5%.0f", sensor_sps30_pm25);
      showDisplayMessage(value);
      break;
    case 8:
      snprintf(value, 32, "PARTICLE SIZE %.0f", sensor_sps30_particle_size);
      showDisplayMessage(value);
      break;
    default:
      segmentDisplay.clear();
      currentScreen = 0;
      break;
  }

  currentScreen++;
  delay(2000);
}

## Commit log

2023-03-25 initial upload
    [KwartzLab-SensorBoard-Rev1-B_Cu.gbr, KwartzLab-SensorBoard-Rev1-B_Mask.gbr, KwartzLab-SensorBoard-Rev1-B_Paste.gbr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]
2023-03-25 adding bom for the board and panel
2023-04-09 Rev 2 Update
    Change Log:
    - added I2C header
    - added GPIO header (IO0, IO4, IO5, IO10)
    - added 10k pull-up on IO8
    - added label on USB C port
    - added kwartzlab logo to the silk screen layer
    - fixed some traces
    [KwartzLab-SensorBoard-Rev1-B_Cu.gbr, KwartzLab-SensorBoard-Rev1-B_Mask.gbr, KwartzLab-SensorBoard-Rev1-B_Paste.gbr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]
2023-04-23 updated a few parts
    [KwartzLab-SensorBoard-Rev3 Panel-B_Mask.gbr, KwartzLab-SensorBoard-Rev3 Panel-Edge_Cuts.gbr, KwartzLab-SensorBoard-Rev3 Panel-F_Mask.gbr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]

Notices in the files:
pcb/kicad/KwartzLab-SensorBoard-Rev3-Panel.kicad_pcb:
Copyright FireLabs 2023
